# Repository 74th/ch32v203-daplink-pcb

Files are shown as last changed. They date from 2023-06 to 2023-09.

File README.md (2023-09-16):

# CH32V203 を利用した DAPLink

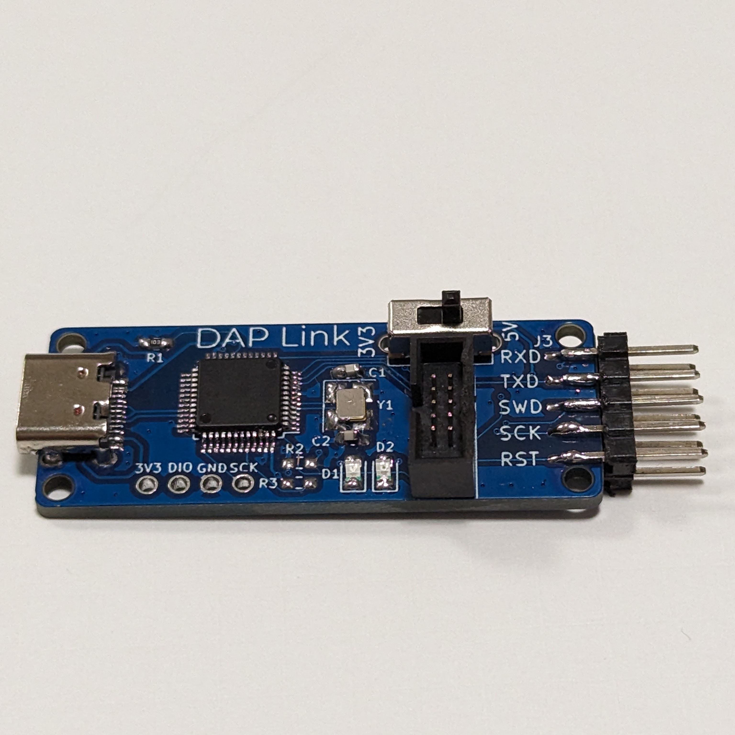
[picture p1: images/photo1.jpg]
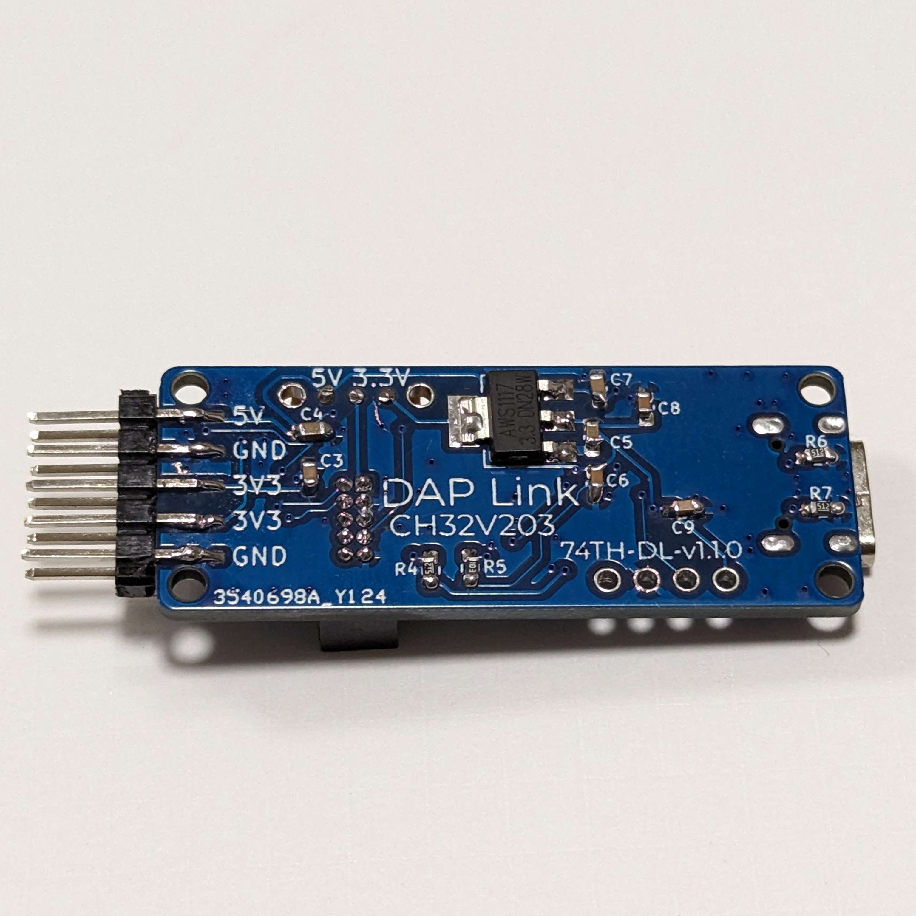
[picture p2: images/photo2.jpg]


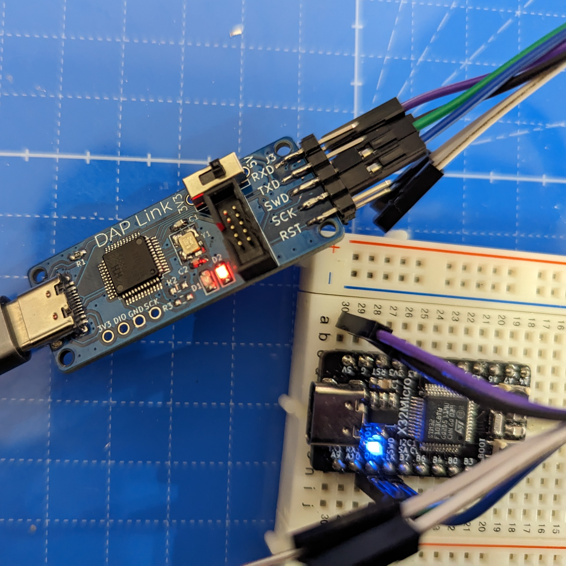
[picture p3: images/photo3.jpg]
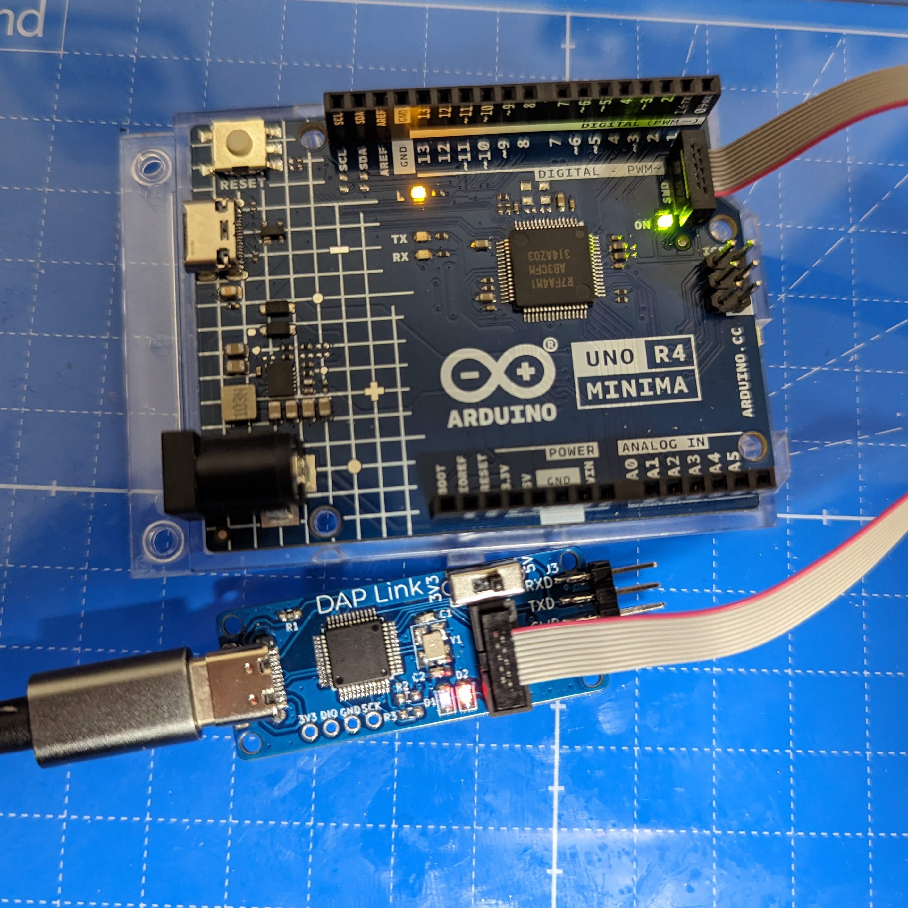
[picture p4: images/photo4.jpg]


- Shop: https://booth.pm/ja/items/4916891

## features

- SWD のデバッガとして使える
- USB シリアル変換として使える
- 1.27mm ピッチ 10 ピンの SWD と互換性のあるポートを持っている（ただし SWO はなし）
- Arduino UNO R4 の SWD + UART の 1.27mm ピッチ 10 ピンと互換性のあるポートを持っている
- 10 ピンコネクタの VCC を 5V、3.3V を切り替えることができる（Arduino UNO R4 では 5V が必要）
- USB-C

## SWD 10pin Connector

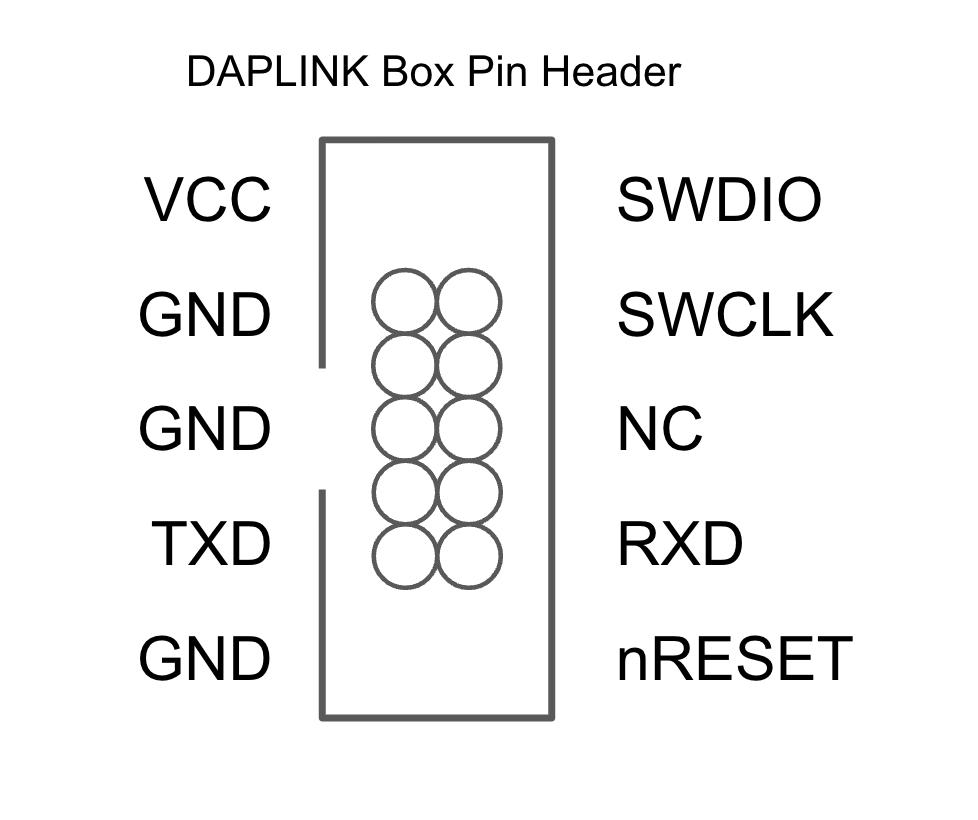
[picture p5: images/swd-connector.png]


## Firmware

https://github.com/XIVN1987/DAPLink/tree/master/CH32V203

## v1.1.0

R2、R3 は NC にすること。

- semantics: [pdf](ch32v203-daplink-v1.1.0-semantics.pdf) [kicanvas](https://kicanvas.org/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)
- pcb: [pdf](ch32v203-daplink-v1.1.0-pcb.pdf) [kicanvas](https://kicanvas.org/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)

## BOM

| Reference  | Name | Quantity |
| --- | --- | --- |
| C1, C2 | Capacitor 0603 22pF | 2 |
| C3, C4, C7 | Capacitor 0603 10uF | 3 |
| C5 | Capacitor 0603 2.2uF | 1 |
| C6, C8, C9 | Capacitor 0603 100nF | 3 |
| D1 | LED 0805 Blue | 1 |
| D2 | LED 0805 Red | 1 |
| J1 | USB Type-C Receptacle | 1 |
| J2 | Box Pin Header 2x5 Pitch 1.27mm | 1 |
| J3 | Pin Header 2x5 Pitch 2.54mm | 1 |
| R1, R5 | Register 0603 10kΩ | 2 |
| R2, R3 | NC | 2 |
| R4, R6, R7 | Register 0603 5.1kΩ | 3 |
| SW1 | Slide Switch | 1 |
| U1 | MCU LQFP48 WCH CH32V203C8T6 | 1 |
| U2 | Regulator 3.3V SOT-223 AMS1117-3.3 | 1 |
| Y1 | Crystal 3225 8MHz | 1 |

## LICENSE

- Firmware: https://github.com/XIVN1987/DAPLink/blob/master/LICENSE
- PCB: MIT

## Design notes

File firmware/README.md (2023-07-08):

以下をビルドしたもの

https://github.com/XIVN1987/DAPLink/tree/master/CH32V203

License MIT

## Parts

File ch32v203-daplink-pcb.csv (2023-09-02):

Reference | Value | Footprint | 数量
C1, C2 | 22p | $74th:Capacitor_0603_1608 | 2
C3, C4, C7 | 10u | $74th:Capacitor_0603_1608 | 3
C5 | 2.2u | $74th:Capacitor_0603_1608 | 1
C6, C8, C9 | 100n | $74th:Capacitor_0603_1608 | 3
CH1 | SWD_WITH_VCC | $74th:SWD-4Pin | 1
D1 | Blue | $74th:LED_0805_2012Metric_Pad1.15x1.40mm_HandSolder | 1
D2 | Red | $74th:LED_0805_2012Metric_Pad1.15x1.40mm_HandSolder | 1
J1 | USB2.0_C_v3 | $74th:USB-C-12-Pin-SMD | 1
J2 | DAPLink-SWD-Send-6Pin | $74th:BoxPinHeader_2x05_P1.27mm_Vertical | 1
J3 | DAPLink-SWD-Send-10Pin | $74th:Side-2x5P-PinHeader-Right | 1
R1, R5 | 10k | $74th:Register_0603_1608 | 2
R2, R3 | 10k(NC) | $74th:Register_0603_1608 | 2
R4, R6, R7 | 5.1k | $74th:Register_0603_1608 | 3
SW1 | SW_SPDT | $74th:Slide_Switch | 1
U1 | CH32V203C8T6 | Package_QFP:LQFP-48_7x7mm_P0.5mm | 1
U2 | AMS1117-3.3 | Package_TO_SOT_SMD:SOT-223-3_TabPin2 | 1
Y1 | 8M | $74th:Crystal_SMD_3225-4Pin_3.2x2.5mm_HandSoldering | 1

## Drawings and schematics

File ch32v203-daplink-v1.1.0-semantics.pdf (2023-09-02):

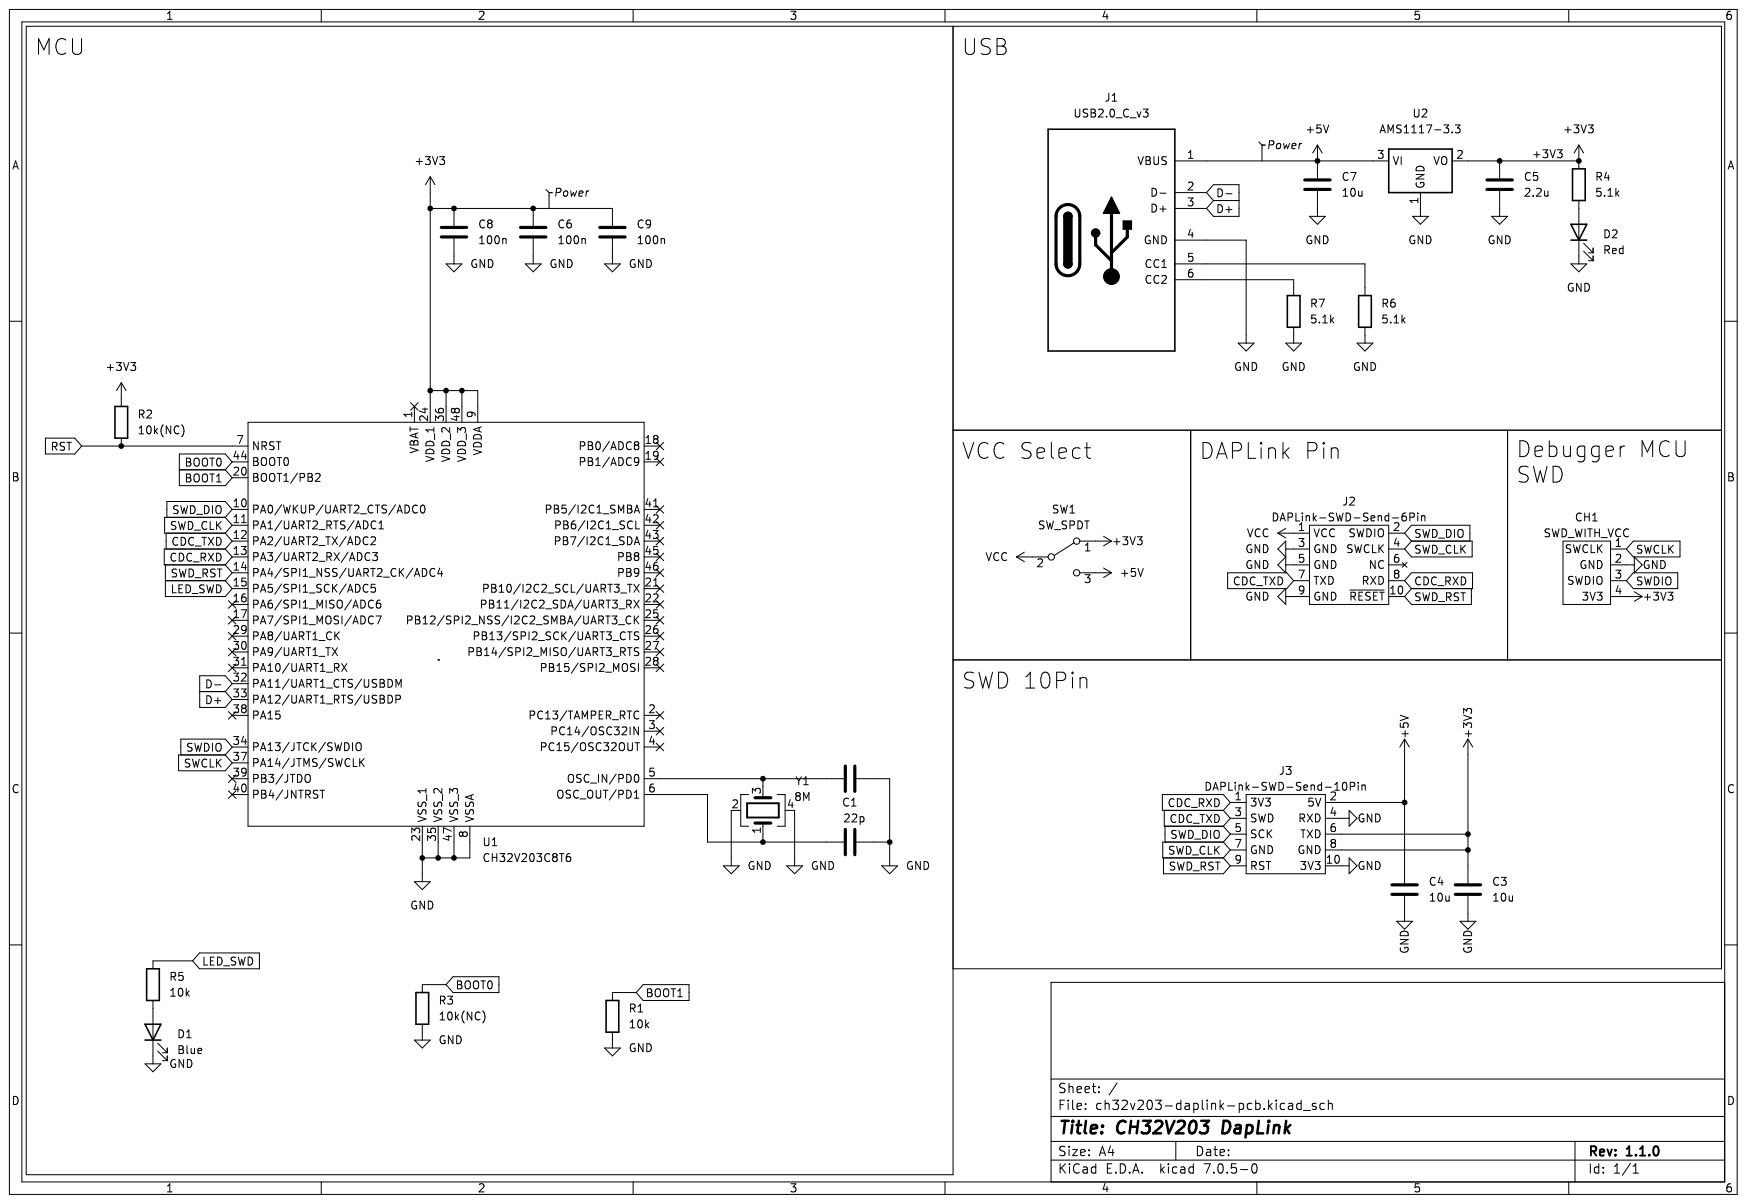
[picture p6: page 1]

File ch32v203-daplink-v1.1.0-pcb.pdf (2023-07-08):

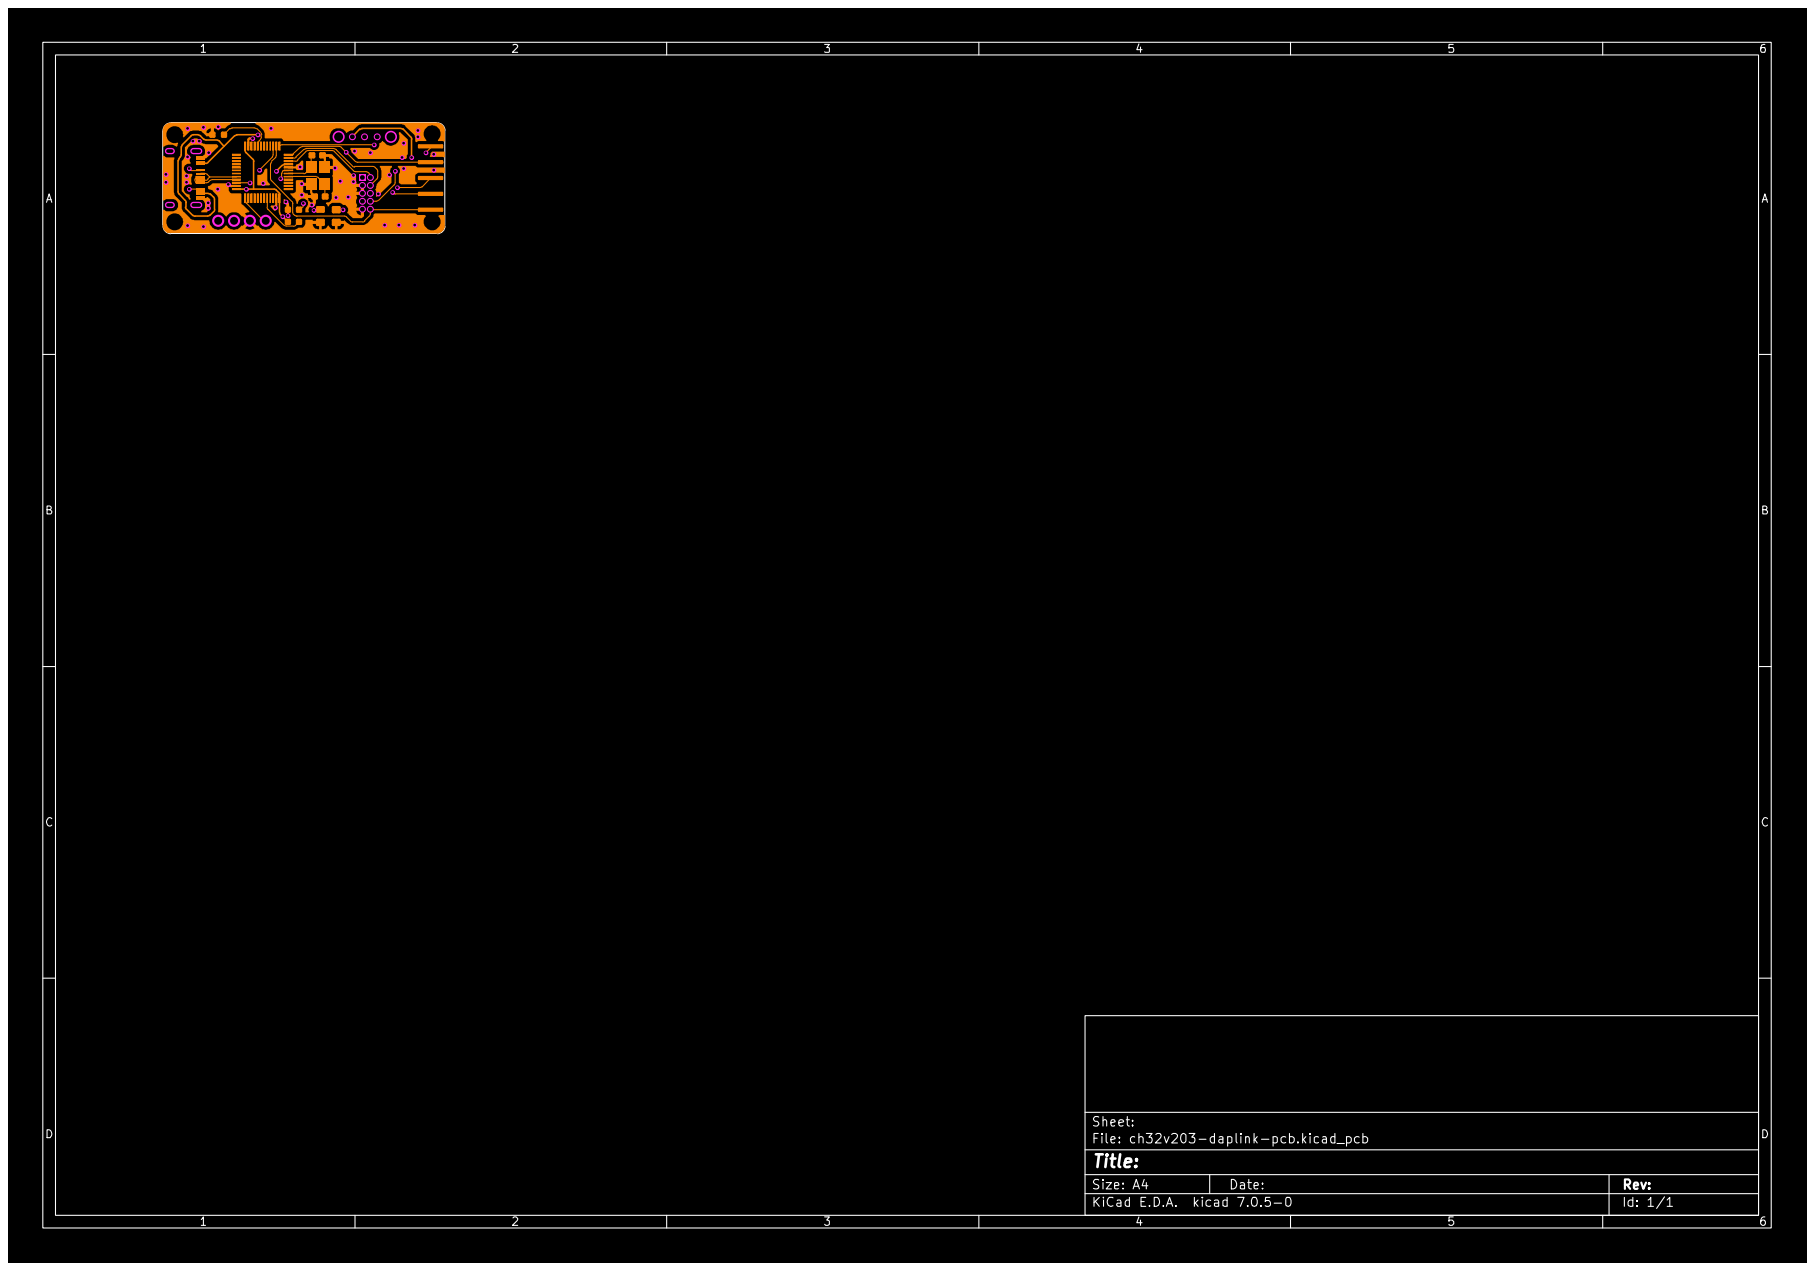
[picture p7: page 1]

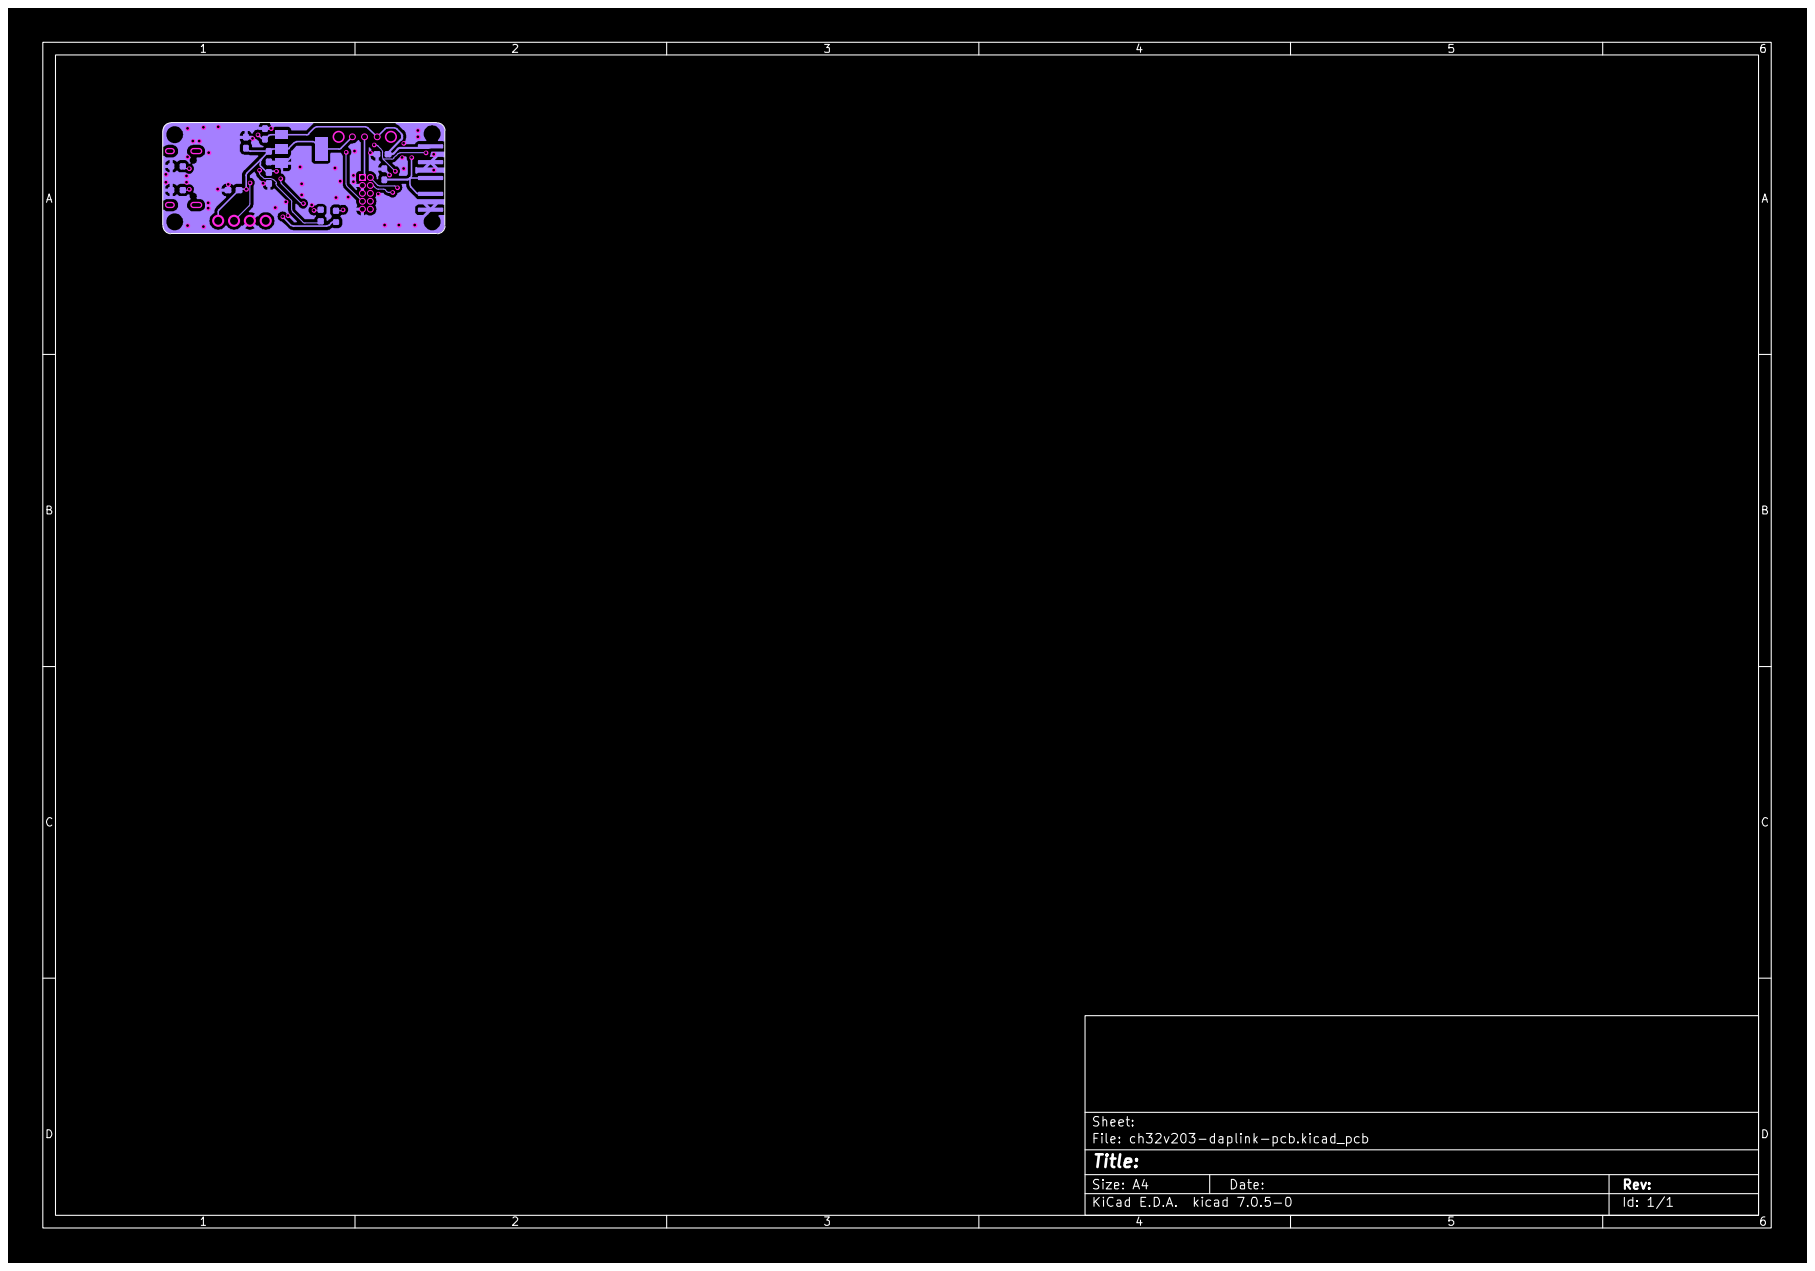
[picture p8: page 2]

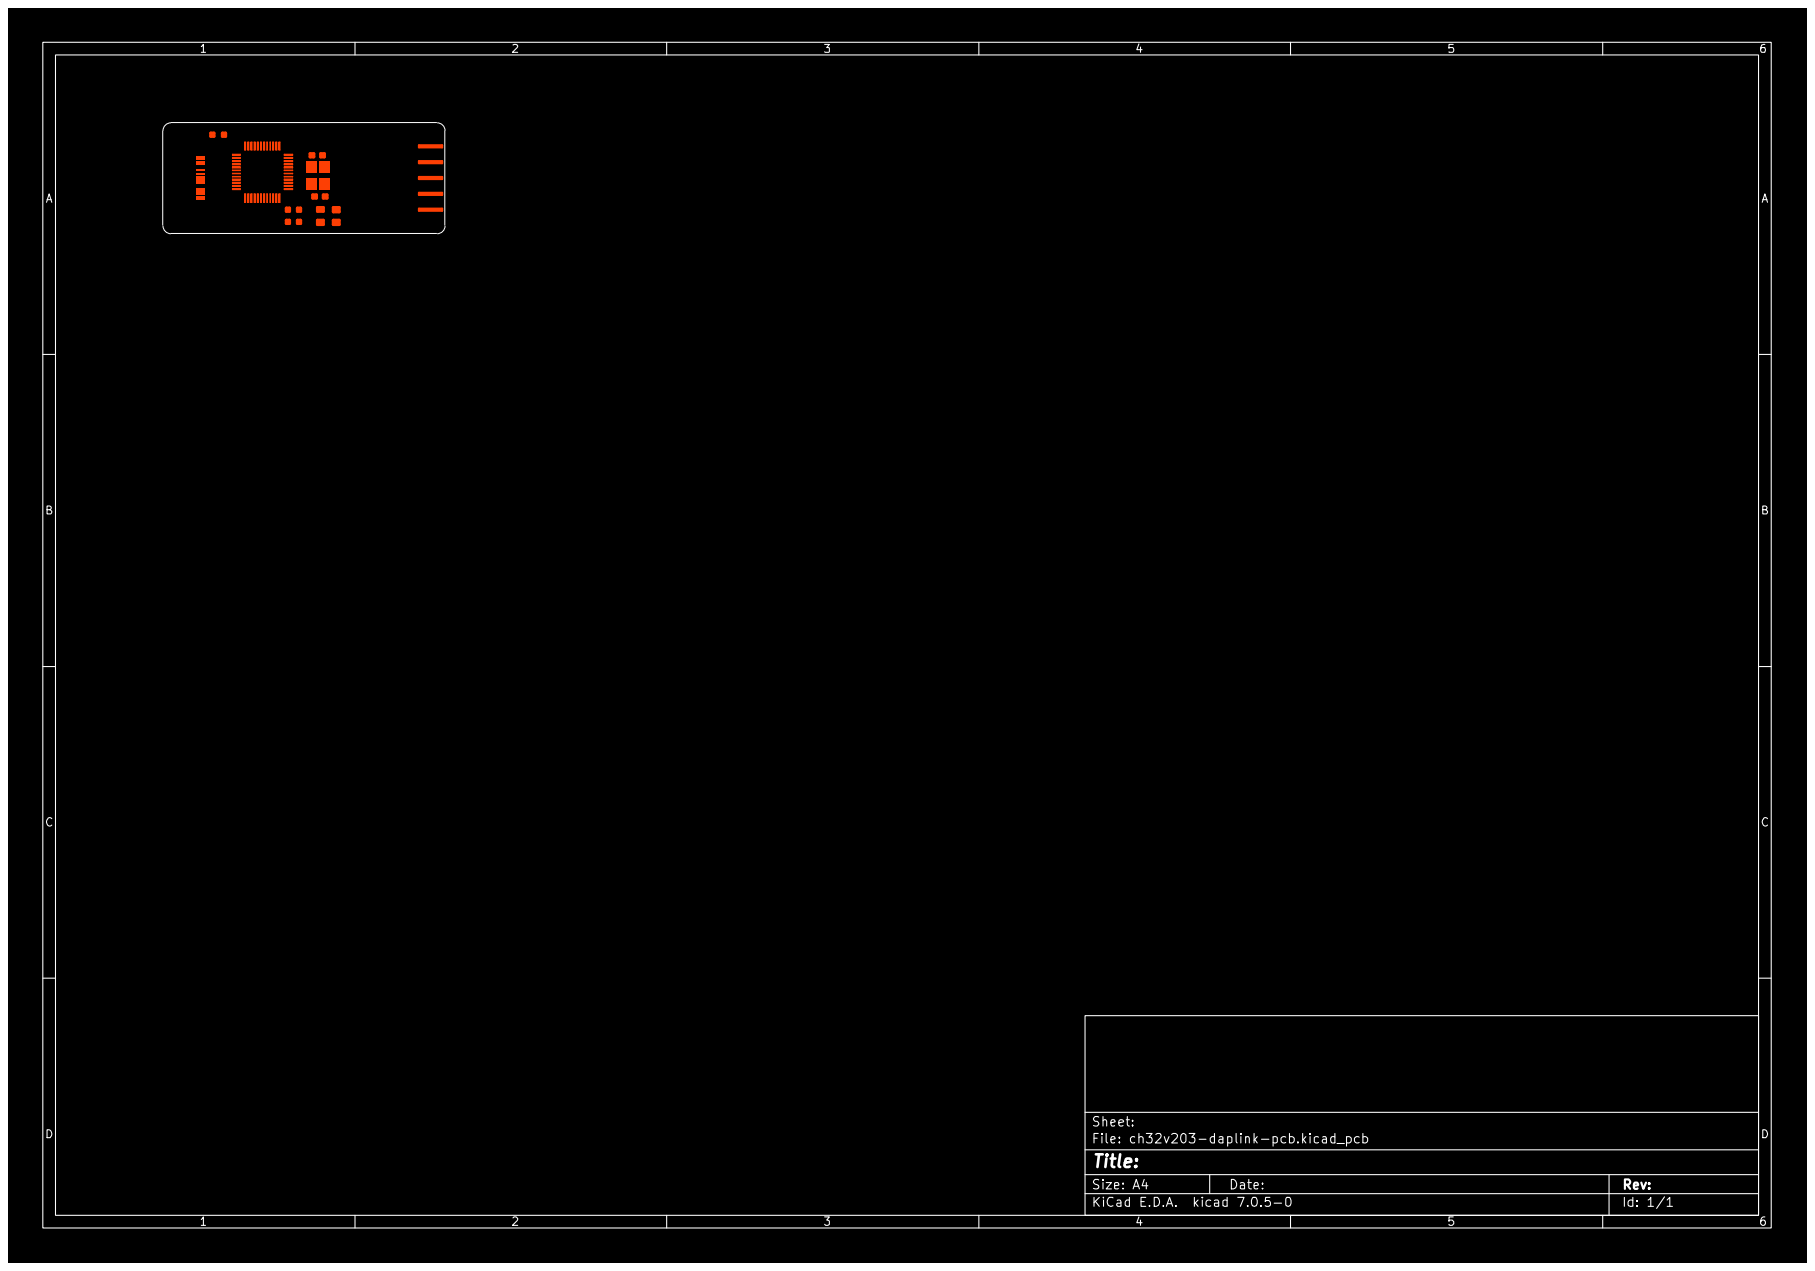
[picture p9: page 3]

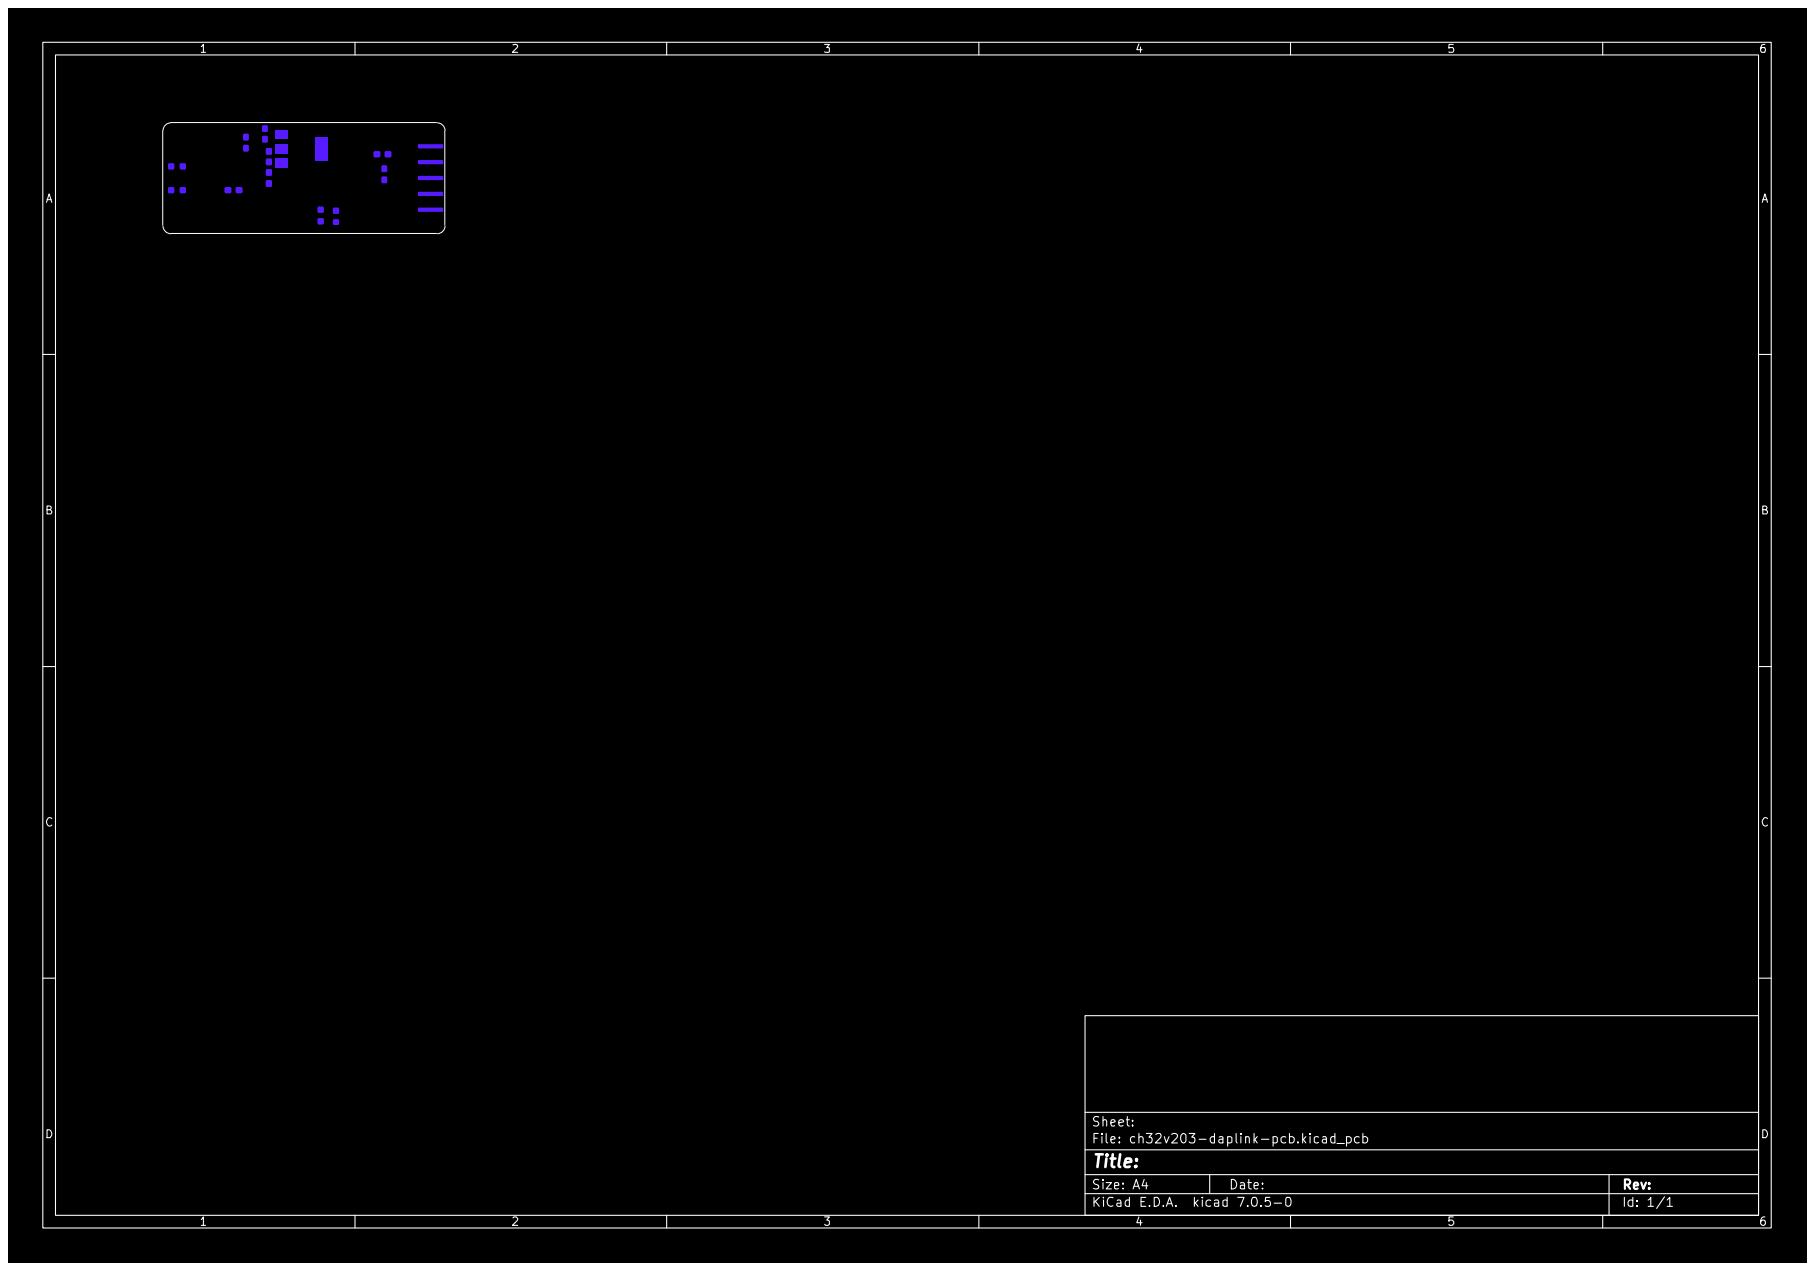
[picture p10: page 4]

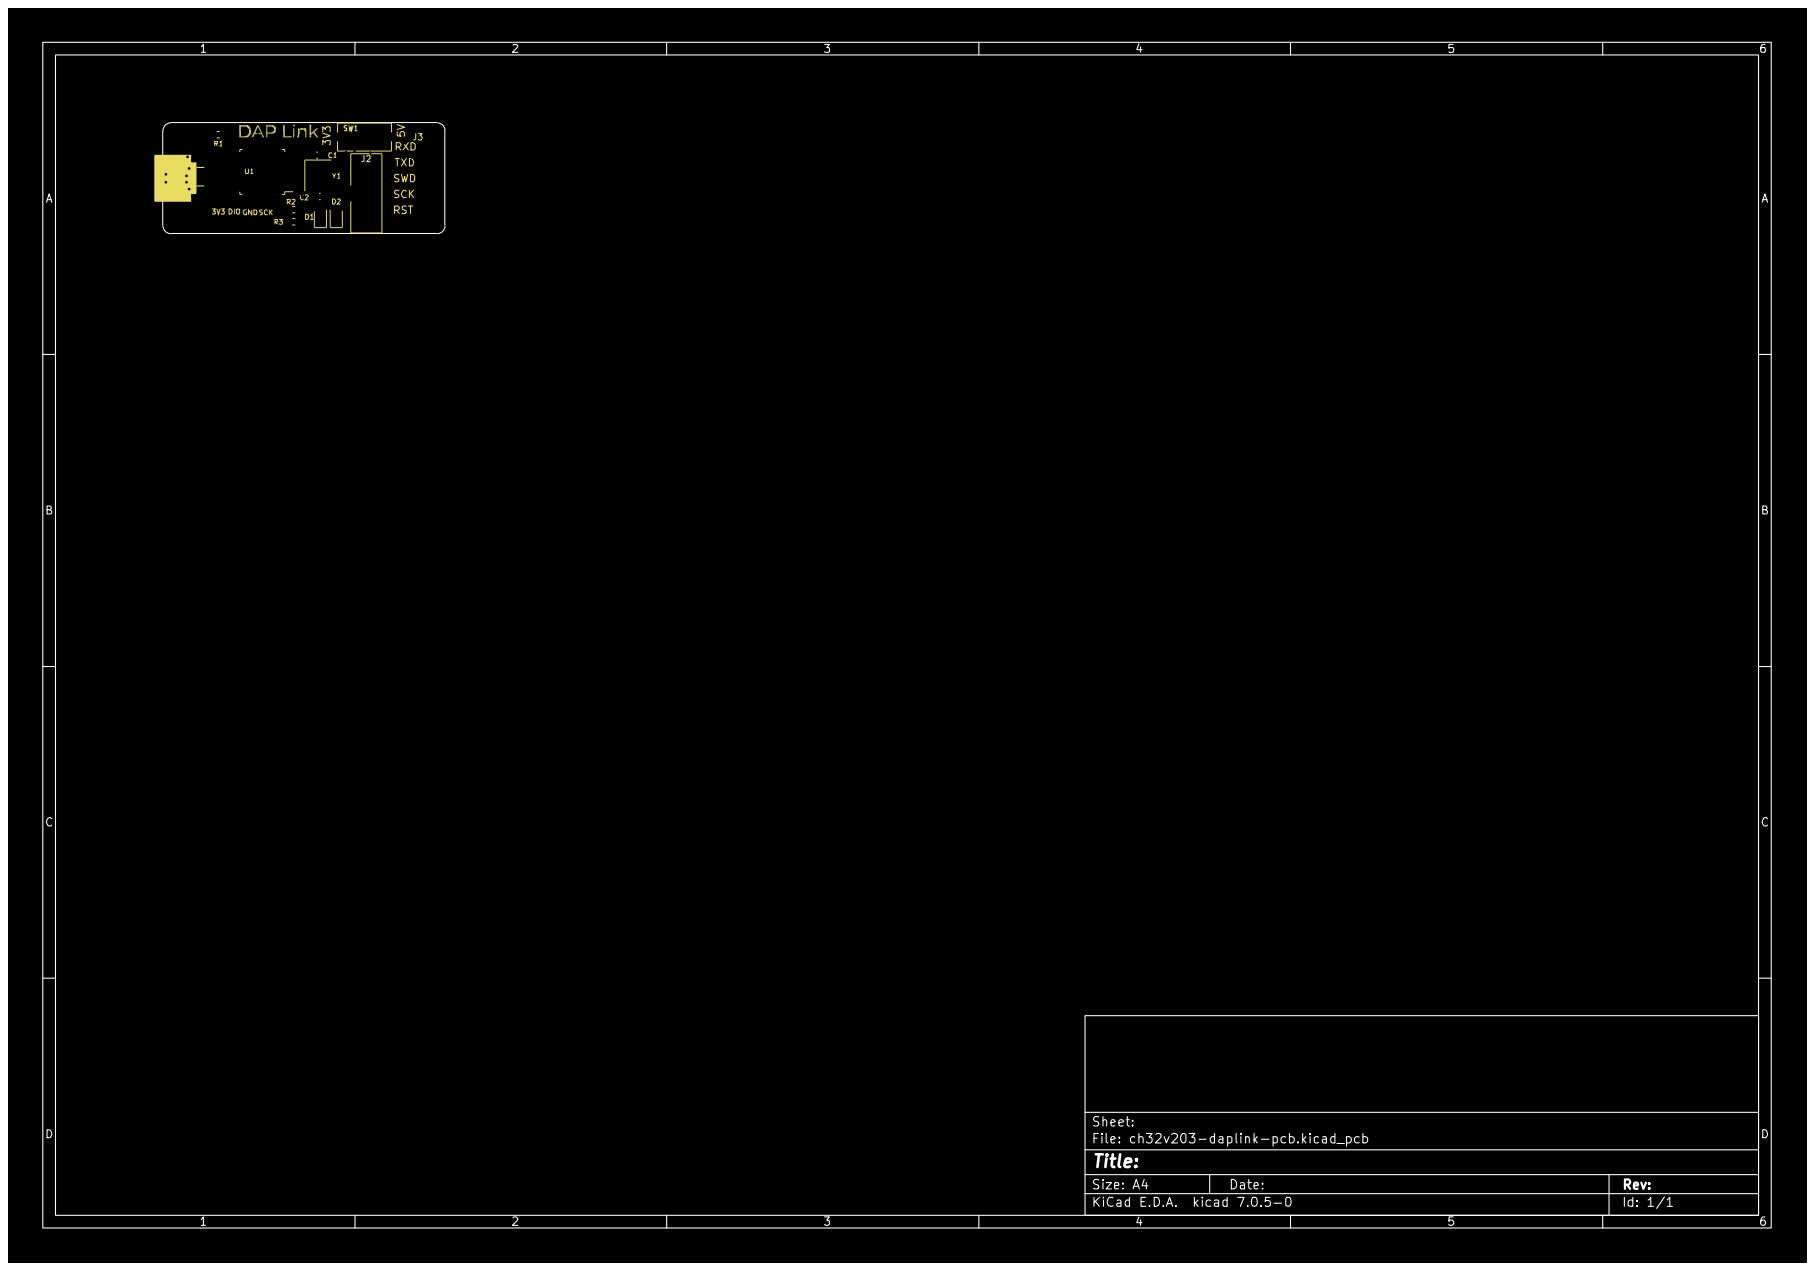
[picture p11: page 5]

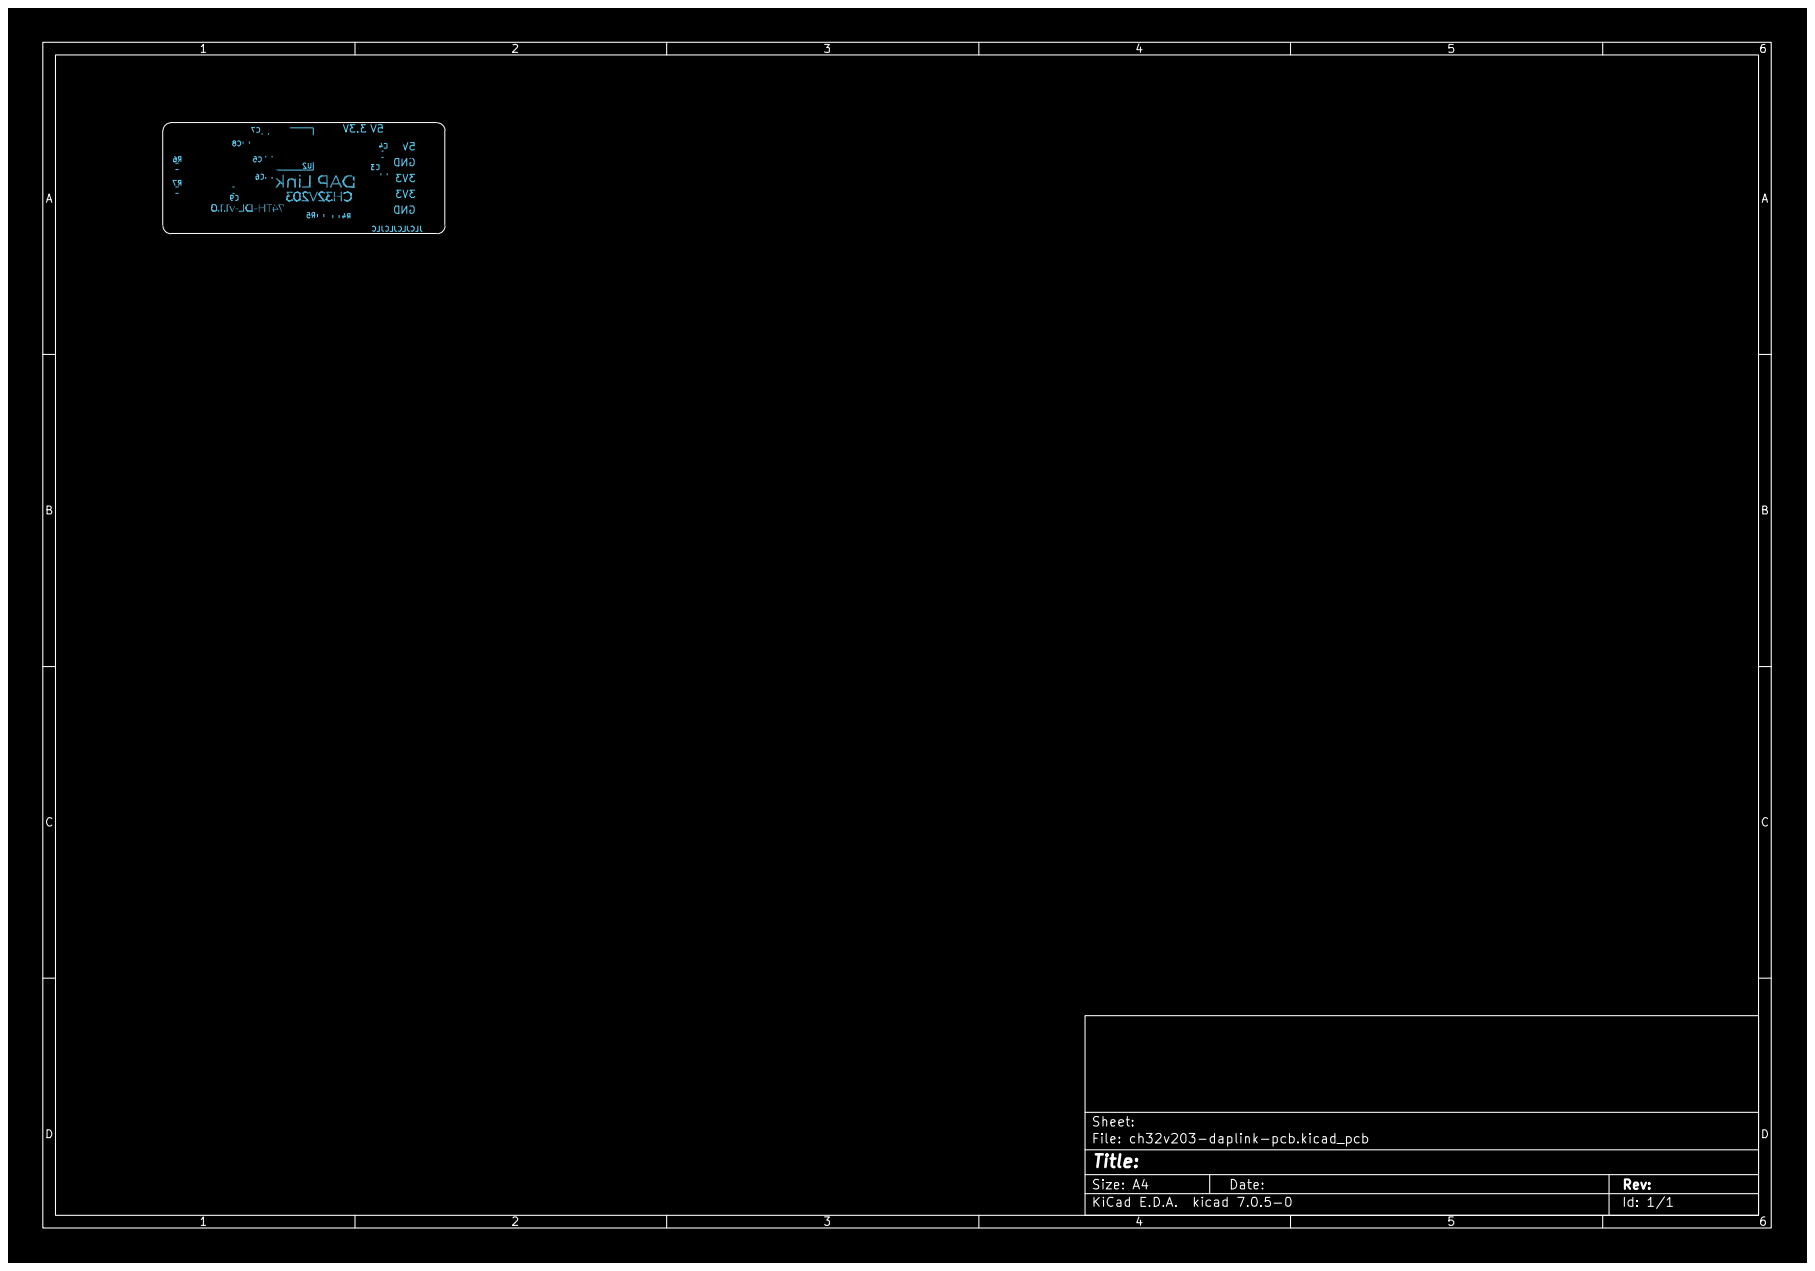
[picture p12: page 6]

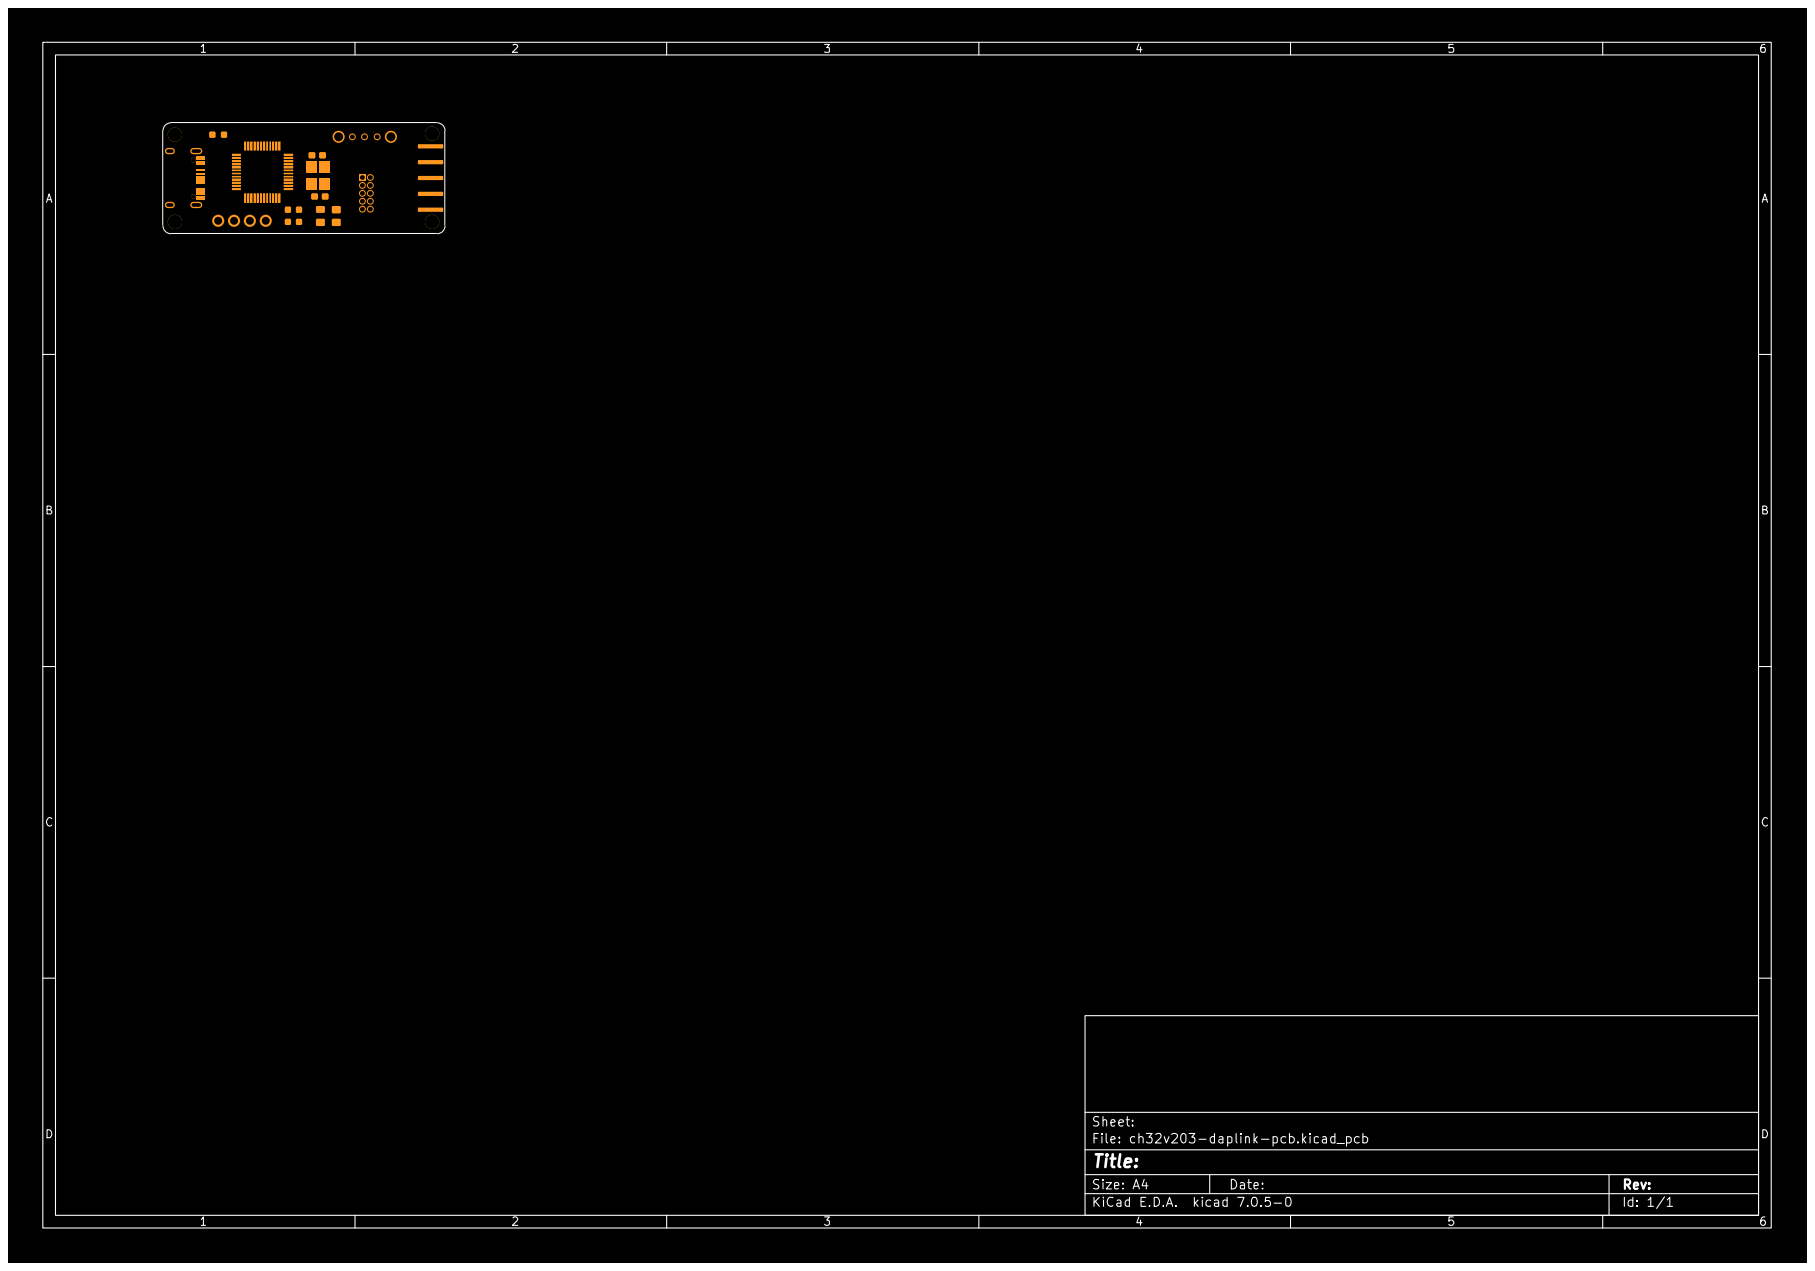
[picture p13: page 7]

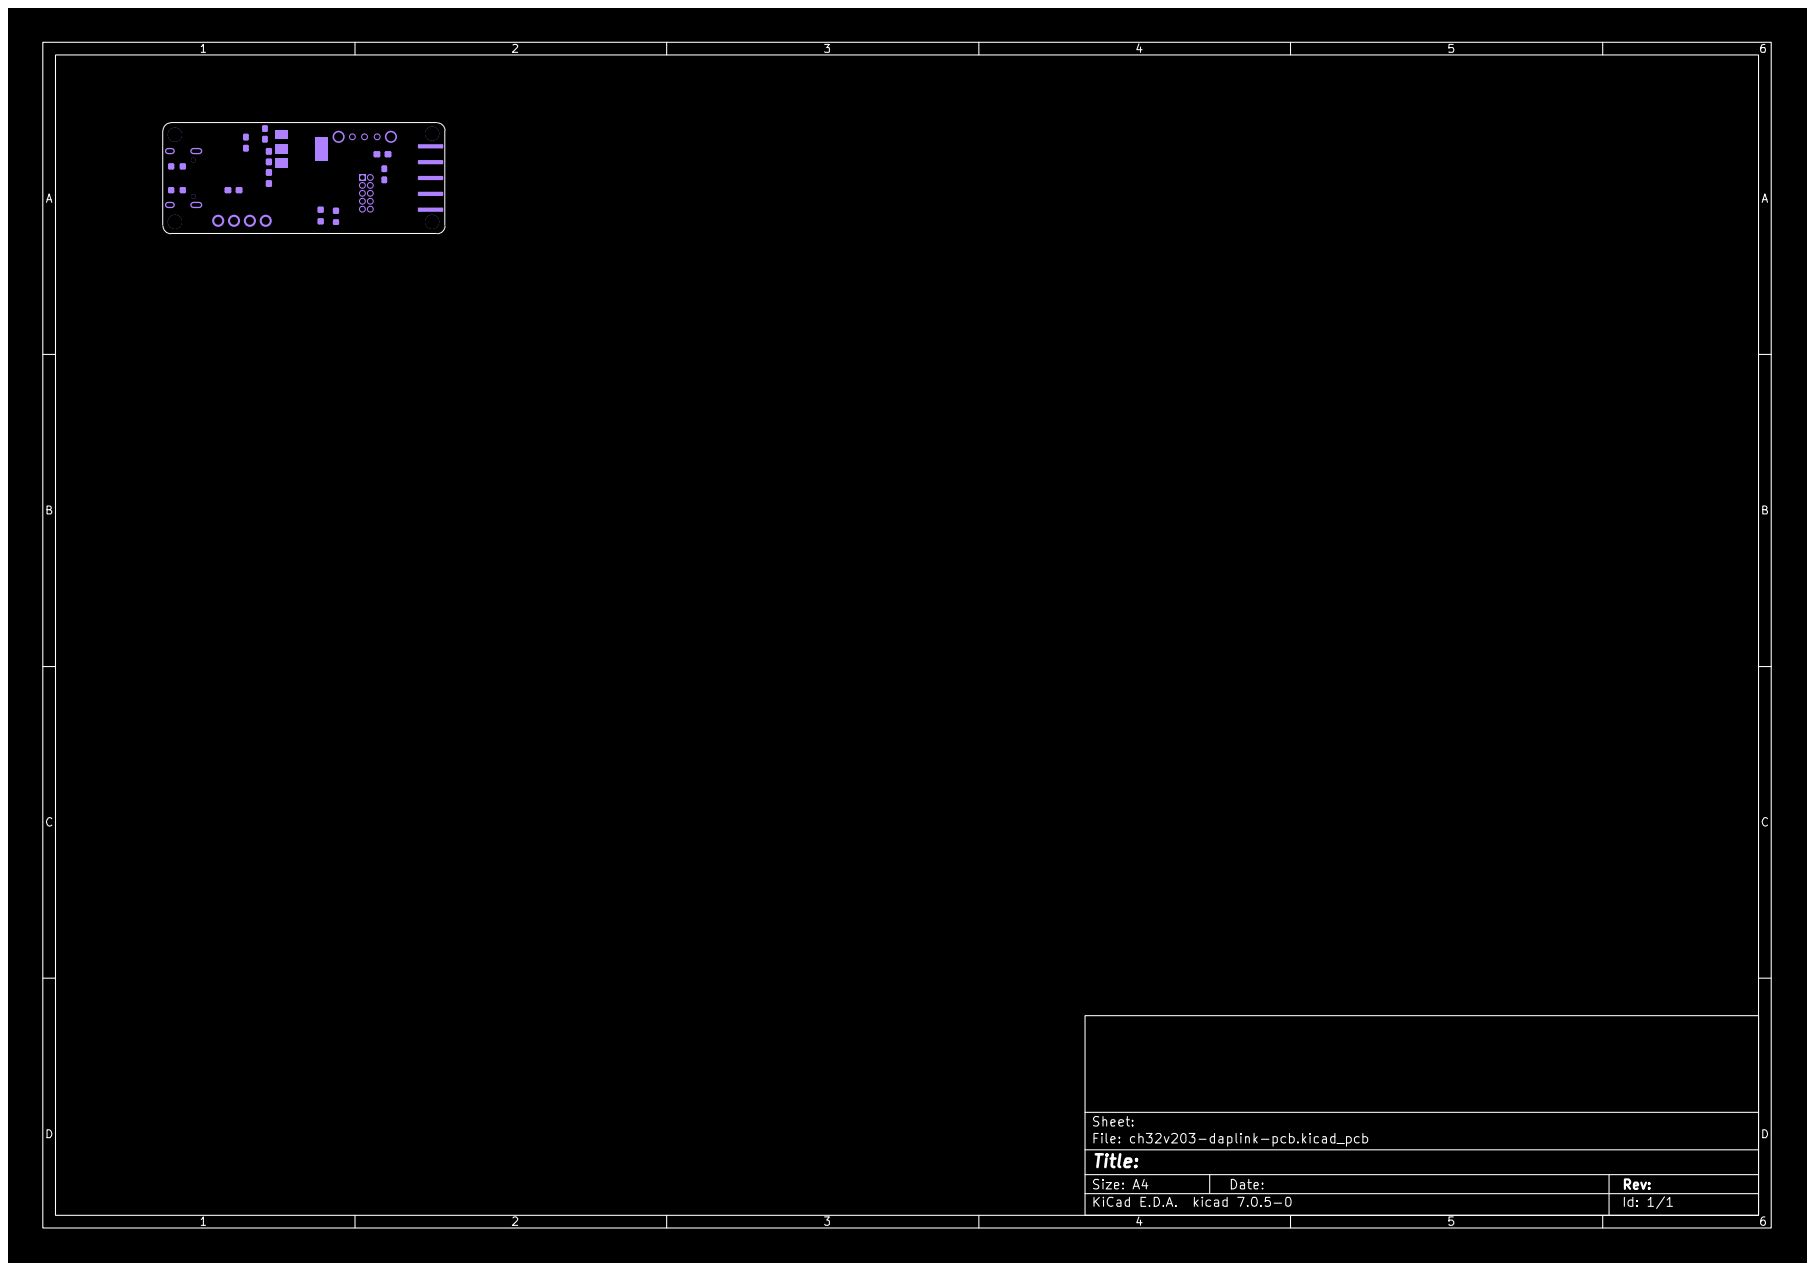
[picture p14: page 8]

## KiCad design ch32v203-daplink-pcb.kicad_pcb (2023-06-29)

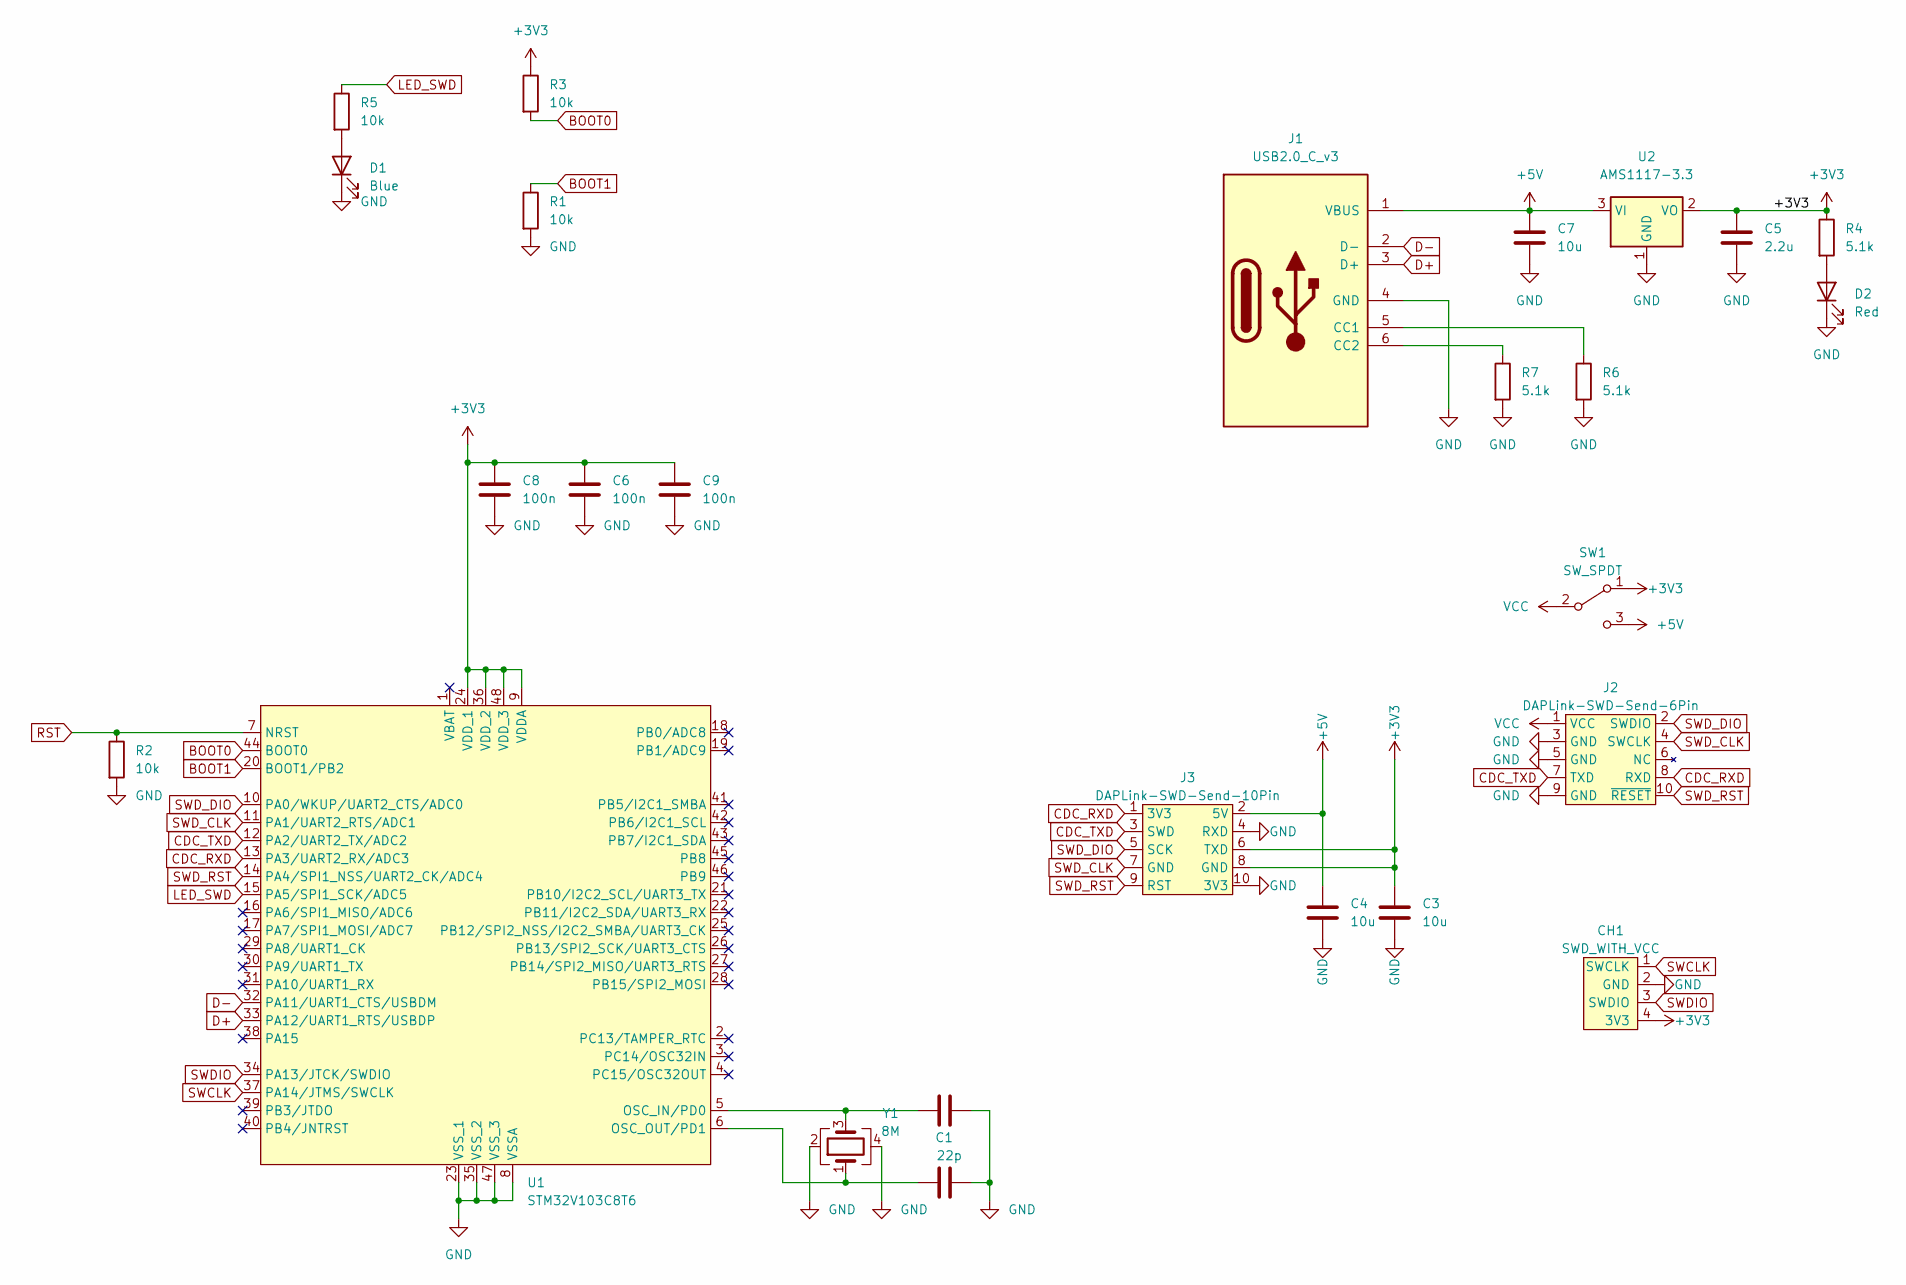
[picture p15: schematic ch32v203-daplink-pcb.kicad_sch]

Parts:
C1, C2: 22p; Capacitor_0603_1608
C3, C4, C7: 10u; Capacitor_0603_1608
C5: 2.2u; Capacitor_0603_1608
C6, C8, C9: 100n; Capacitor_0603_1608
CH1: SWD_WITH_VCC; SWD-4Pin
D1: Blue; LED_0805_2012Metric_Pad1.15x1.40mm_HandSolder
D2: Red; LED_0805_2012Metric_Pad1.15x1.40mm_HandSolder
J1: USB2.0_C_v3; USB-C-12-Pin-SMD
J2: DAPLink-SWD-Send-6Pin; BoxPinHeader_2x05_P1.27mm_Vertical
J3: DAPLink-SWD-Send-10Pin; Side-2x5P-PinHeader-Right
R1, R2, R3, R5: 10k; Register_0603_1608
R4, R6, R7: 5.1k; Register_0603_1608
SW1: SW_SPDT; Slide_Switch
U1: STM32V103C8T6; LQFP-48_7x7mm_P0.5mm
U2: AMS1117-3.3; SOT-223-3_TabPin2
Y1: 8M; Crystal_SMD_3225-4Pin_3.2x2.5mm_HandSoldering

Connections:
+3V3: C3.1, C5.1, C6.1, C8.1, C9.1, CH1.4 (3V3), J3.6 (TXD), J3.8 (GND), R3.1, R4.1, SW1.1 (A), U1.9 (VDDA), U1.24 (VDD_1), U1.36 (VDD_2), U1.48 (VDD_3), U2.2 (VO)
+5V: C4.1, C7.1, J1.1 (VBUS), J3.2 (5V), SW1.3 (C), U2.3 (VI)
BOOT0: R3.2, U1.44 (BOOT0)
BOOT1: R1.1, U1.20 (BOOT1/PB2)
CDC_RXD: J2.8 (RXD), J3.1 (3V3), U1.13 (PA3/UART2_RX/ADC3)
CDC_TXD: J2.7 (TXD), J3.3 (SWD), U1.12 (PA2/UART2_TX/ADC2)
D+: J1.3 (D+), U1.33 (PA12/UART1_RTS/USBDP)
D-: J1.2 (D-), U1.32 (PA11/UART1_CTS/USBDM)
GND: C1.2, C2.2, C3.2, C4.2, C5.2, C6.2, C7.2, C8.2, C9.2, CH1.2 (GND), D1.1 (K), D2.1 (K), J1.4 (GND), J2.3 (GND), J2.5 (GND), J2.9 (GND), J3.4 (RXD), J3.10 (3V3), R1.2, R2.2, R6.2, R7.2, U1.8 (VSSA), U1.23 (VSS_1), U1.35 (VSS_2), U1.47 (VSS_3), U2.1 (GND), Y1.2, Y1.4
LED_SWD: R5.1, U1.15 (PA5/SPI1_SCK/ADC5)
unnamed: D2.2 (A), R4.2
unnamed: D1.2 (A), R5.2
unnamed: J1.5 (CC1), R6.1
unnamed: J1.6 (CC2), R7.1
unnamed: C2.1, U1.5 (OSC_IN/PD0), Y1.3
unnamed: C1.1, U1.6 (OSC_OUT/PD1), Y1.1
RST: R2.1, U1.7 (NRST)
SWCLK: CH1.1 (SWCLK), U1.37 (PA14/JTMS/SWCLK)
SWDIO: CH1.3 (SWDIO), U1.34 (PA13/JTCK/SWDIO)
SWD_CLK: J2.4 (SWCLK), J3.7 (GND), U1.11 (PA1/UART2_RTS/ADC1)
SWD_DIO: J2.2 (SWDIO), J3.5 (SCK), U1.10 (PA0/WKUP/UART2_CTS/ADC0)
SWD_RST: J2.10 (~RESET), J3.9 (RST), U1.14 (PA4/SPI1_NSS/UART2_CK/ADC4)
VCC: J2.1 (VCC), SW1.2 (B)

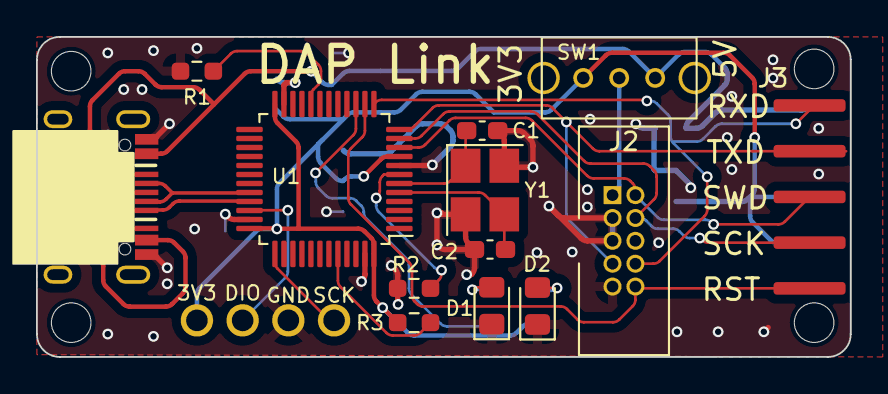
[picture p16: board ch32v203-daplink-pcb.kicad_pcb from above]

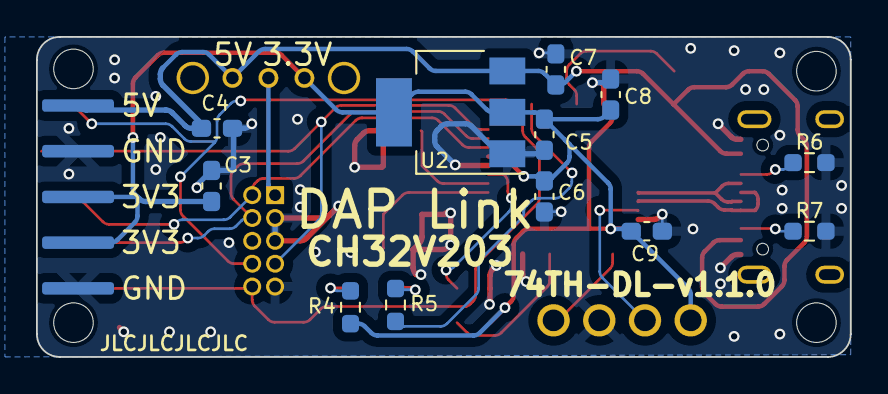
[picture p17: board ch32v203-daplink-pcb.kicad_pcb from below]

Board: 2 copper layers, 45.2 x 17.8 mm, 30 parts (12 on the bottom side), 23 nets.

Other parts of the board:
M1, M2, M3, M4: M2-Hole

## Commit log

2023-06-28 for Arduino UNO R4
    [ch32v203-daplink-pcb.kicad_pcb, ch32v203-daplink-pcb.kicad_sch]
2023-09-02 fix semantics
    [ch32v203-daplink-pcb.csv, ch32v203-daplink-pcb.kicad_sch]
